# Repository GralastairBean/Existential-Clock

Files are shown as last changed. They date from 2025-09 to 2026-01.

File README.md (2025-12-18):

### Overview
### Calculations
### Printing
### Wiring
### BOM

part,USD,qty,total,link

case\_front, $0.48 ,1, $0.48 ,

case\_back, $0.25 ,1, $0.25 ,

USB TYPE-C conversion board 2.54MM CC1 CC2 5.1K pull-down resistor connection, $0.68 ,1, $0.68 ,https://www.aliexpress.com/item/1005005777382409.html?spm=a2g0o.order\_list.order\_list\_main.11.48fd1802CWoXaq ,

arduino nano clone, $5.33 ,1, $5.33 ,https://www.amazon.com/dp/B07G99NNXL?ref=ppx\_yo2ov\_dt\_b\_fed\_asin\_title ,

Adafruit DS3231 Precision RTC Breakout, $17.50 ,1, $17.50 ,https://www.adafruit.com/product/3013?srsltid=AfmBOorY5\_5bFqTH8Gmqvp4xZocum8U0b0bRwiaDY5xZqLUaMxEYaVcX ,

CR1220 3V Lithium Coin Cell, $2.56 ,1, $2.56 ,https://www.hktvmall.com/hktv/en/main/Galaxy-Digital/s/H5239001/Home-Appliances/Home-Appliances/Other-Small-Home-Appliances-%26-Accessories/Drill-%26-Extension-Cord-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\_S\_MURATA\_CR1220\_5pcs ,

Red 4 Common Cathode 0.36 Through Hole LED Character and Numeric RoHS, $0.64 ,3, $1.92 ,https://www.lcsc.com/product-detail/C10708.html ,

MAX7219CNG 7-segment display drivers, $1.99 ,2, $3.98 ,https://www.amazon.com/dp/B0BK6XC4P8?ref=ppx\_yo2ov\_dt\_b\_fed\_asin\_title ,

"cermaic capacitor (1 per driver IC) = 0.1uF = 100nf = ""104""", $-   ,2, $-   ,

electrolytic capacitor (at main power supply) = 10uF, $-   ,1, $-   ,

resistors (current limiting 1 per driver IC) = 10k, $-   ,2, $-   ,

m3x3mm threaded inserts , $0.11 ,10, $1.10 ,https://cnckitchen.store/products/heat-set-insert-m3-x-3-short-version-100-pieces ,

m3x6mm bolts  (to fasten DISPLAY pcb to case), $0.04 ,4, $0.16 ,

m3x6mm bolts  (to fasten USB-C breakout to case), $0.04 ,2, $0.08 ,

m3x6mm bolts  (to fasten back and front case together), $0.04 ,2, $0.08 ,

m3x5mm bolts  (to fasten CONTROL pcb to case), $0.04 ,2, $0.08 ,

JST HX 2.54mm 5 pin connection wire (display PCB to control PCB), $1.00 ,1, $1.00 ,https://www.amazon.com/dp/B0CM315RFP?ref=ppx\_yo2ov\_dt\_b\_fed\_asin\_title ,

JST HX 2.54mm 2 pin connection wire (USB-C to control board), $0.50 ,1, $0.50 ,https://www.amazon.com/dp/B0CM315RFP?ref=ppx\_yo2ov\_dt\_b\_fed\_asin\_title ,

JST HX 5 pin male , $0.15 ,2, $0.30 ,https://www.amazon.com/dp/B0CM315RFP?ref=ppx\_yo2ov\_dt\_b\_fed\_asin\_title ,

JST HX 2 pin male , $0.15 ,2, $0.30 ,https://www.amazon.com/dp/B0CM315RFP?ref=ppx\_yo2ov\_dt\_b\_fed\_asin\_title ,

,,,,

total cost,,34, $35.57 ,

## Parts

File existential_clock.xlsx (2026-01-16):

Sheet: maths
type | value | digits
age | 35 | 2
MAOD | 80 | 2
years | 45 | 2
summers | 45 | 2
months | 540 | 3
days | 16425 | 5 | 5
hours | 394200 | 6 | 2
minutes | 23652000 | 8 | 2
seconds | 1419120000 | 10 | 2
death | 2070

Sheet: bom
part | USD | qty | total | link
case_front | $0.48 | 1 | $0.48
case_back | $0.25 | 1 | $0.25
USB TYPE-C conversion board 2.54MM CC1 CC2 5.1K pull-down resistor connection | $0.68 | 1 | $0.68 | https://www.aliexpress.com/item/1005005777382409.html
arduino nano clone | $5.33 | 1 | $5.33 | https://www.amazon.com/dp/B07G99NNXL?ref=ppx_yo2ov_dt_b_fed_asin_title
Adafruit DS3231 Precision RTC Breakout | $17.50 | 1 | $17.50 | https://www.adafruit.com/product/3013
CR1220 3V Lithium Coin Cell | $2.56 | 1 | $2.56 | https://www.hktvmall.com/hktv/en/main/Galaxy-Digital/s/H5239001/Home-Appliances/Home-Appliances/Other-Small-Home-Appliances-%26-Accessories/Drill-%26-Extensio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
Red 4 Common Cathode 0.36 Through Hole LED Character and Numeric RoHS | $0.64 | 3 | $1.92 | https://www.lcsc.com/product-detail/C10708.html
MAX7219CNG 7-segment display drivers | $1.99 | 2 | $3.98 | https://www.amazon.com/dp/B0BK6XC4P8?ref=ppx_yo2ov_dt_b_fed_asin_title
cermaic capacitor (1 per driver IC) = 0.1uF = 100nf = "104" | $0.00 | 2 | $0.00
electrolytic capacitor (at main power supply) = 10uF | $0.00 | 1 | $0.00
resistors (current limiting 1 per driver IC) = 10k | $0.00 | 2 | $0.00
m3x3mm threaded inserts | $0.11 | 10 | $1.10 | https://cnckitchen.store/products/heat-set-insert-m3-x-3-short-version-100-pieces
m3x6mm bolts (to fasten DISPLAY pcb to case) | $0.04 | 4 | $0.16
m3x6mm bolts (to fasten USB-C breakout to case) | $0.04 | 2 | $0.08
m3x6mm bolts (to fasten back and front case together) | $0.04 | 2 | $0.08
m3x5mm bolts (to fasten CONTROL pcb to case) | $0.04 | 2 | $0.08
JST HX 2.54mm 5 pin connection wire (display PCB to control PCB) | $1.00 | 1 | $1.00 | https://www.amazon.com/dp/B0CM315RFP?ref=ppx_yo2ov_dt_b_fed_asin_title
JST HX 2.54mm 2 pin connection wire (USB-C to control board) | $0.50 | 1 | $0.50 | https://www.amazon.com/dp/B0CM315RFP?ref=ppx_yo2ov_dt_b_fed_asin_title
JST HX 5 pin male | $0.15 | 2 | $0.30 | https://www.amazon.com/dp/B0CM315RFP?ref=ppx_yo2ov_dt_b_fed_asin_title
JST HX 2 pin male | $0.15 | 2 | $0.30 | https://www.amazon.com/dp/B0CM315RFP?ref=ppx_yo2ov_dt_b_fed_asin_title
total cost |  | 34 | $35.57

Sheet: dataBase
now: | 1767688140 | << ENTER
for issues per SN see github
SN | colour | owner | RTC_set | LE | deathDate | unixTime | remain
01 | red | ali | 2026-01-06 | 83 | 2073-11-22 | 3278505600 | 1510817460
02 | red | div | 2025-12-30 | 81 | 2070-06-01 | 3168777600 | 1401089460
03 | white | test | 2026-01-06 | 83 | 2073-11-22 | 3278505600 | 1510817460
04 | red | dad | 2026-01-06 | 84 | 2042-07-13 | 2288793600 | 521105460

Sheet: printing
part | material | profile | walls | infill | notes
case_back | PLA | 0.2 structural | 4 | 15
case_front | PLA | 0.2 structural | 4 | 15 | bed temp 70C for adhesion

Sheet: testing
go to: | https://www.unixtimestamp.com/
death: | 3278505600 | DateTime deathTime value from code
now: | 1767366150 | enter this value
delta: | 1511139450 | this should be the display
start: | 2025-12-30
 |  | Delta T (sec)
check ID | date | SN01 | SN02 | SN03 | up-time (days)
1 | 2025-12-30 | 0.0 | 0.0 | 0.0 | 0
2 | 2026-01-02 | 0.0 | 0.5 | 0.5 | 3
3
4
5
6
7
8
9
10
11
12
13
14
15
16
17
18

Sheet: pinout
SEGMENTS |  |  |  |  | 7-SEGMENT DISPLAY PINOUT
each driver connects its segment driver pin to both segment pins on the display baords e.g. SEGA->a
U1 | DISP1 | DISP2 | U2 | DISP3
SEGA | a | a | SEGA | a | 12 | 11 | 10 | 9 | 8 | 7
SEGB | b | b | SEGB | b
SEGC | c | c | SEGC | c |  | FRONT
SEGD | d | d | SEGD | d
SEGE | e | e | SEGE | e
SEGF | f | f | SEGF | f
SEGG | g | g | SEGG | g | 1 | 2 | 3 | 4 | 5 | 6
SEGDP | dp | dp | SEGDP | dp
DIGITS
Each driver connects its digit pins to the G pins of the display baords
Note the drivers go from DIG0-DIG7 = can drive max 8 segments
Corresponding G pins start at 1 so connections staggered by 1
U1 | DISP1 | DISP2 | U2 | DISP3
DIG0 | G1 |  | DIG0 | G1
DIG1 | G2 |  | DIG1 | G2
DIG2 | G3 |  | DIG2 | G3
DIG3 | G4 |  | DIG3 | G4
DIG4 |  | G1 | DIG4
DIG5 |  | G2 | DIG5
DIG6 |  | G3 | DIG6
DIG7 |  | G4 | DIG7
DATA
Arduino -> header -> U1_DIN -U1_DOUT -> U2_DIN
Data flows from Arduino to first driver then out to second driver
header | U1 | U2
pin 3 | DIN
 | DOUT | DIN

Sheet: wiring
USB-C | 5V rail | GND rail | Arduino | DISP | RTC
VBUS | 5V |  | 5V | VCC | 5V
GND |  | GND | GND | GND | GND
 |  |  | A5 |  | SCL
 |  |  | A4 |  | SDA
 |  |  | D7 | DIN
 |  |  | D6 | CLK
 |  |  | D5 | CS

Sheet: power
Red 7 segment
brightness | V (V) | I (mA) | P (mW)
0 | 5.1 | 36 | 183.6
1 | 5.1 | 51 | 260.1
2 | 5.1 | 64 | 326.4
3 | 5.1 | 75 | 382.5
4 | 5.1 | 93 | 474.3
5 | 5.1 | 109 | 555.9
6 | 5.1 | 125 | 637.5
7 | 5.1 | 135 | 688.5
8 | 5.1 | 149 | 759.9
9 | 5.1 | 161 | 821.1
10 | 5.1 | 173 | 882.3
11 | 5.1 | 190 | 969
12 | 5.1 | 205 | 1045.5
13 | 5.1 | 217 | 1106.7
14 | 5.1 | 228 | 1162.8
15 | 5.1 | 240 | 1224

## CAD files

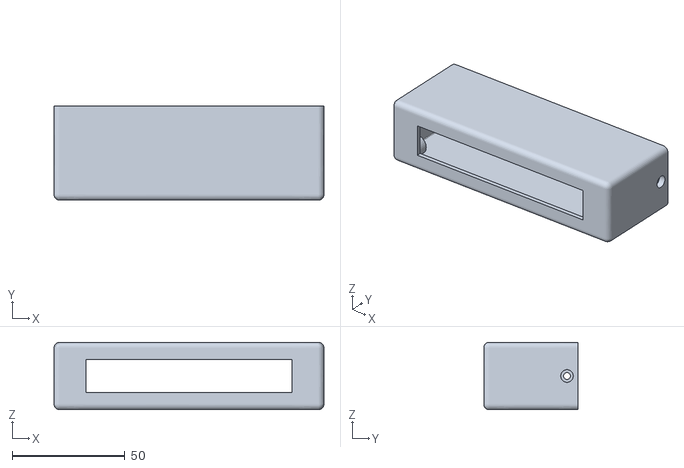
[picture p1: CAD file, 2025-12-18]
hardware/case_front.stl
120.0 x 42.0 x 30.0

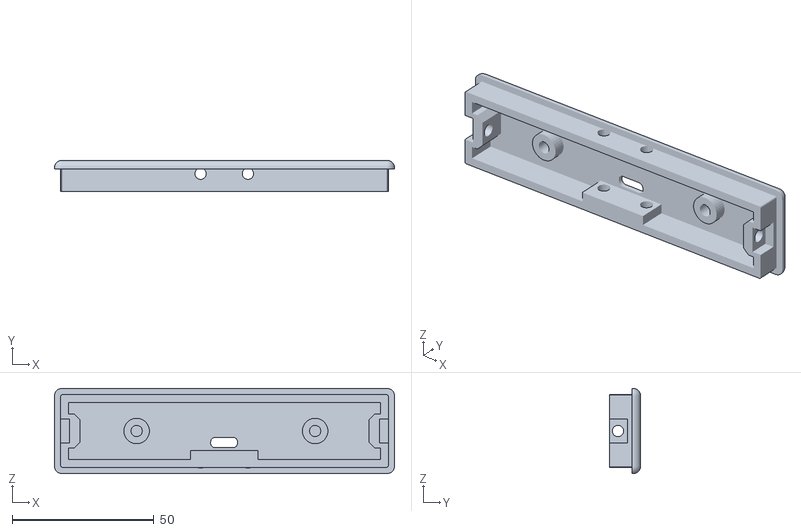
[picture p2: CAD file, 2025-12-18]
hardware/case_back.stl
120.0 x 11.0 x 30.0

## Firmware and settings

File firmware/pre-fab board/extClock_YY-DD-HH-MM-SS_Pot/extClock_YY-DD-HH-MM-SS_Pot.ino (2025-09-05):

#include <LedControl.h>
#include <Wire.h>
#include <RTClib.h>

#define DIN_PIN 11
#define CS_PIN 10
#define CLK_PIN 13
#define POT_PIN A0 // potentiometer input

LedControl lc = LedControl(DIN_PIN, CLK_PIN, CS_PIN, 2); 
RTC_DS3231 rtc;

// Example "death date"
DateTime deathTime(2070, 12, 31, 0, 0, 0);

// --- Brightness smoothing variables ---
const int SMOOTH_SAMPLES = 3;      // fewer samples = snappier response
int potBuffer[SMOOTH_SAMPLES];     // readings buffer
int bufferIndex = 0;               // circular buffer index
long bufferTotal = 0;              // sum of stored readings

void setup() {
  Serial.begin(9600); // serial monitor for debugging

  if (!rtc.begin()) {
    while (true); // Stop if RTC not found
  }

  // Initialize brightness buffer with initial pot value
  int initialPot = analogRead(POT_PIN);
  for (int i = 0; i < SMOOTH_SAMPLES; i++) {
    potBuffer[i] = initialPot;
    bufferTotal += initialPot;
  }

  for (int module = 0; module < 2; module++) {
    lc.shutdown(module, false);
    lc.setIntensity(module, 2); // initial brightness
    lc.clearDisplay(module);
  }
}

void printToDisplay(const char *buf) {
  int len = strlen(buf);
  int pos = 0;
  for (int i = len - 1; i >= 0; i--) {
    char c = buf[i];
    int module = 1 - pos / 8;
    int digit = pos % 8;

    if (c == '-') {
      lc.setChar(module, digit, '-', false);
    } else if (c >= '0' && c <= '9') {
      lc.setDigit(module, digit, c - '0', false);
    } else {
      lc.setChar(module, digit, ' ', false);
    }
    pos++;
  }
  for (; pos < 16; pos++) {
    int module = 1 - pos / 8;
    int digit = pos % 8;
    lc.setChar(module, digit, ' ', false);
  }
}

void displayCountdown(TimeSpan remaining) {
  long totalDays = remaining.days();
  int years = totalDays / 365;
  int days = totalDays % 365;
  int hours = remaining.hours();
  int mins = remaining.minutes();
  int secs = remaining.seconds();

  char buf[20];
  snprintf(buf, sizeof(buf), "%02d-%03d-%02d-%02d-%02d",
           years, days, hours, mins, secs);

  printToDisplay(buf);
}

void loop() {
  // --- Smooth brightness control ---
  int newReading = analogRead(POT_PIN);

  bufferTotal -= potBuffer[bufferIndex];
  potBuffer[bufferIndex] = newReading;
  bufferTotal += newReading;

  bufferIndex = (bufferIndex + 1) % SMOOTH_SAMPLES;

  int averageReading = bufferTotal / SMOOTH_SAMPLES;

  int brightness = (averageReading * 15L) / 1010;

  for (int module = 0; module < 2; module++) {
    lc.setIntensity(module, brightness);
  }

  // Debug output of current brightness
  Serial.print("Pot raw: ");
  Serial.print(newReading);
  Serial.print(" | Smoothed: ");
  Serial.print(averageReading);
  Serial.print(" | Brightness: ");
  Serial.println(brightness);

  // --- Countdown display ---
  DateTime now = rtc.now();

  if (now >= deathTime) {
    printToDisplay("00-000-00-00-00");
  } else {
    TimeSpan remaining = deathTime - now;
    displayCountdown(remaining);
  }

  delay(10); // faster refresh for brightness control
}

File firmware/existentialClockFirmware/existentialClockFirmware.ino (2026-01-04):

// BETA TESTING FIRMWARE
// Fixed brightness (no photo‑resistor)
// RTC calculated time to live

#define FIRMWARE_VERSION "0.2.0" //change this at each new release

#include <Wire.h>
#include <RTClib.h>
#include "LedControl.h"

LedControl lc = LedControl(7, 6, 5, 2); // Arduino pins: D7=DIN, D6=CLK, D5=LOAD/CS, 2=2x7219 driver chips
RTC_DS3231 rtc;

int fixedBrightness = 0; // set the fixed brightness: 0 (dimmest) to 15 (brightest)

DateTime deathTime(2073, 11, 22, 00, 00, 00);  // (year, month, day, hour...) of death

void setup() {
  Serial.begin(9600);
  if (!rtc.begin()) {
  Serial.println("RTC init fail, check connections");
  delay(1000);  // give time to send before blocking
  while (1);
  }
  Serial.print("Existential Clock Firmware Version ");
  Serial.println(FIRMWARE_VERSION);

  TimeSpan remaining = deathTime - rtc.now();

  Serial.print("RTC Time: ");
  Serial.print(rtc.now().day()); Serial.print("/");
  Serial.print(rtc.now().month()); Serial.print("/");
  Serial.print(rtc.now().year()); Serial.print(" ");
  Serial.print(rtc.now().hour()); Serial.print(":");
  Serial.print(rtc.now().minute()); Serial.print(":");
  Serial.println(rtc.now().second());

  Serial.print("Death Time: ");
  Serial.print(deathTime.day()); Serial.print("/");
  Serial.print(deathTime.month()); Serial.print("/");
  Serial.print(deathTime.year()); Serial.print(" ");
  Serial.print(deathTime.hour()); Serial.print(":");
  Serial.print(deathTime.minute()); Serial.print(":");
  Serial.println(deathTime.second());

  Serial.print("Seconds to death: ");
  Serial.println((unsigned long)remaining.totalseconds());

  for (int i = 0; i < 2; i++) {
    lc.shutdown(i, false);
    lc.clearDisplay(i);
    lc.setIntensity(i, fixedBrightness);
  }
}

// Show number with dots every 3 digits
void displayNumber(unsigned long long val) {
  int digits[12];
  for (int i = 0; i < 12; i++) {
    digits[i] = val % 10;
    val /= 10;
  }

  bool leading = true;
  for (int i = 11; i >= 0; i--) {
    int d = digits[i];
    int dev = (11 - i) / 8;
    int pos = (11 - i) % 8;
    bool dp = (i % 3 == 0 && i != 0);

    if (leading && d == 0)
      lc.setChar(dev, pos, ' ', false);
    else {
      lc.setDigit(dev, pos, d, dp);
      leading = false;
    }
  }
}

void loop() {
  static int lastSecond = -1;

  DateTime current = rtc.now();
  int sec = current.second();

  if (sec != lastSecond) {  // only run once per new RTC second
    lastSecond = sec;

    if (current >= deathTime) {
      for (int i = 0; i < 2; i++) lc.clearDisplay(i);
      while (1);  // stop execution permanently
    }

    TimeSpan remaining = deathTime - current;
    unsigned long long totalSecs = remaining.totalseconds();
    displayNumber(totalSecs);
  }

  delay(50);  // modest polling rate for I²C, adjust 20–100 ms if desired
}

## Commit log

2021-09-21 import existential clock v1 code base and sort file structure
    [MATH.xlsx]
2021-09-30 add millis function to update the age and display
2021-09-30 adjusted code for testing millis() function
2021-10-13 fix Serial Print debug output
2023-11-14 add pulsing LED to show operation
2023-11-15 add pulsing heartbeat LED on PWM pin 9
2023-11-15 add wiring to pre-amble
2024-06-22 update age to current age
2025-09-12 add pot brightness control and use millis not delay
2025-12-02 make fixed brightness a variable
    [allUpTest_3_fixedBrightness.ino]
2025-12-04 print data to serial for debug
2025-12-04 RTC fail serial output
    [allUpTest_3_fixedBrightness.ino]
2025-12-18 add step and stl files
    [case_back.stl, case_front.stl]
2025-12-30 change update logic from internal oscillator based using millis to using the RTC seconds
    [allUpTest_3_fixedBrightness.ino]
2026-01-04 folder renaming v3 to nil
    [case_back.stl, case_front.stl]
